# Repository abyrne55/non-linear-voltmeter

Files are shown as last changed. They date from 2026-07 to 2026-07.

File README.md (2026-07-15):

# Non-linear Voltmeter

Arduino-driven 0-16 V panel meter with a Gaussian-weighted non-linear scale that expands resolution around 12 V — designed for monitoring a 12 V DC bus (e.g. Synology NAS power rail).

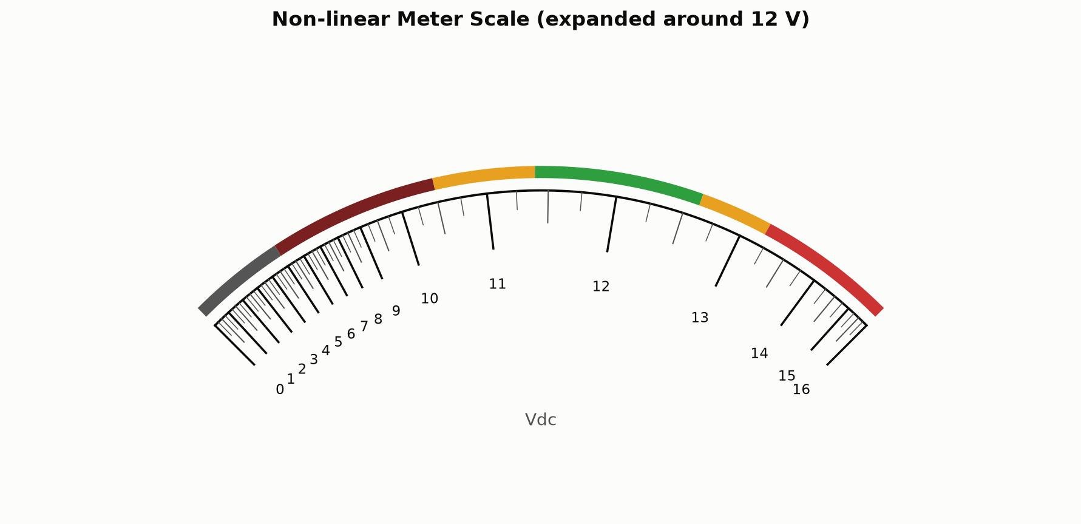
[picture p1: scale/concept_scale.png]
Meter scale


## Circuit

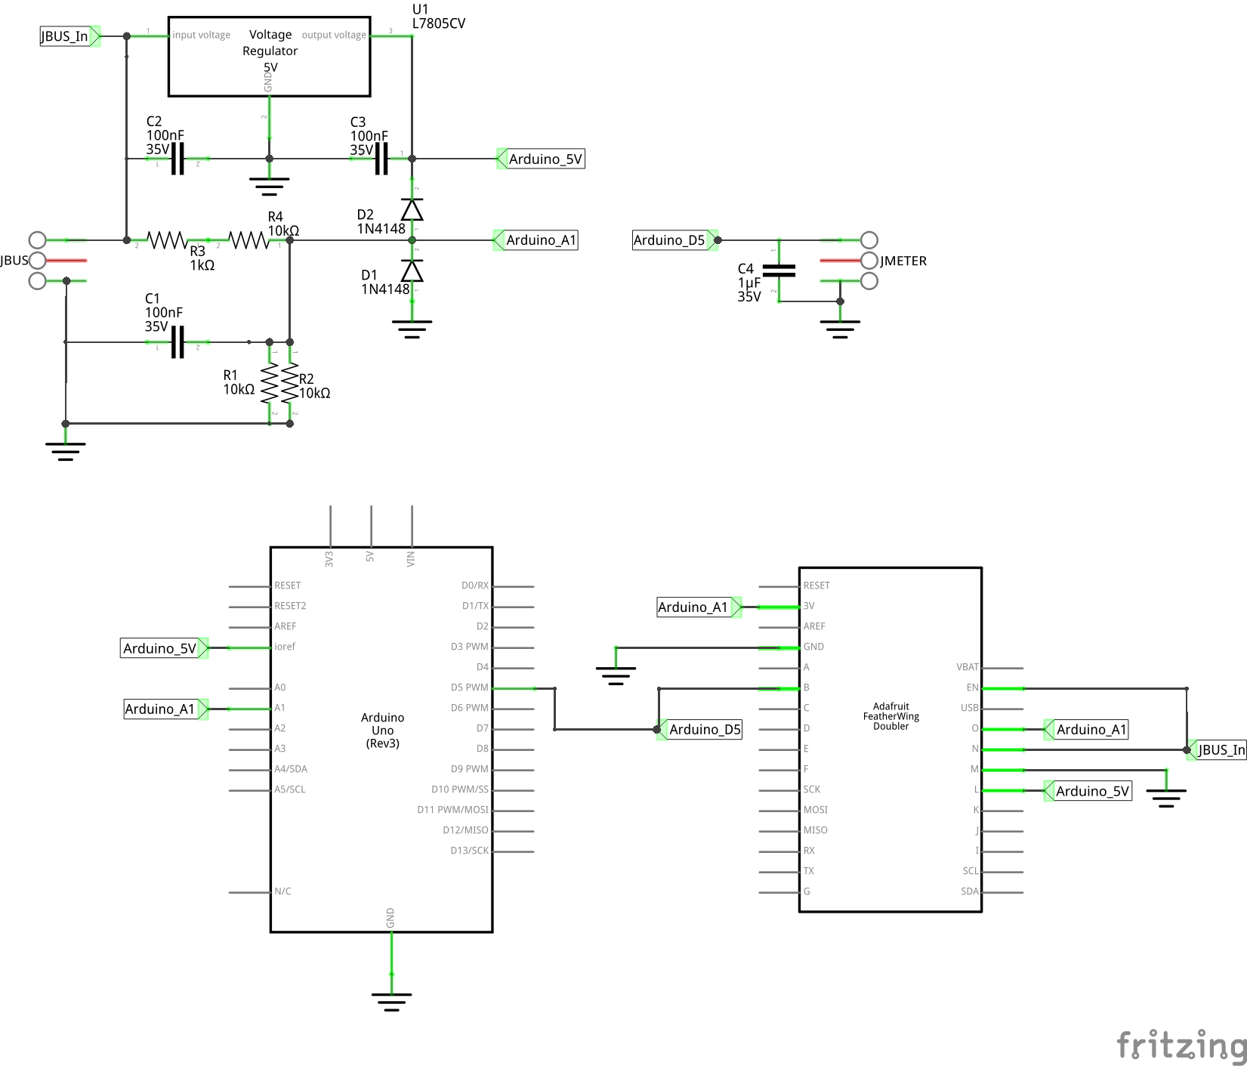
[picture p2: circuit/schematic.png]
Schematic


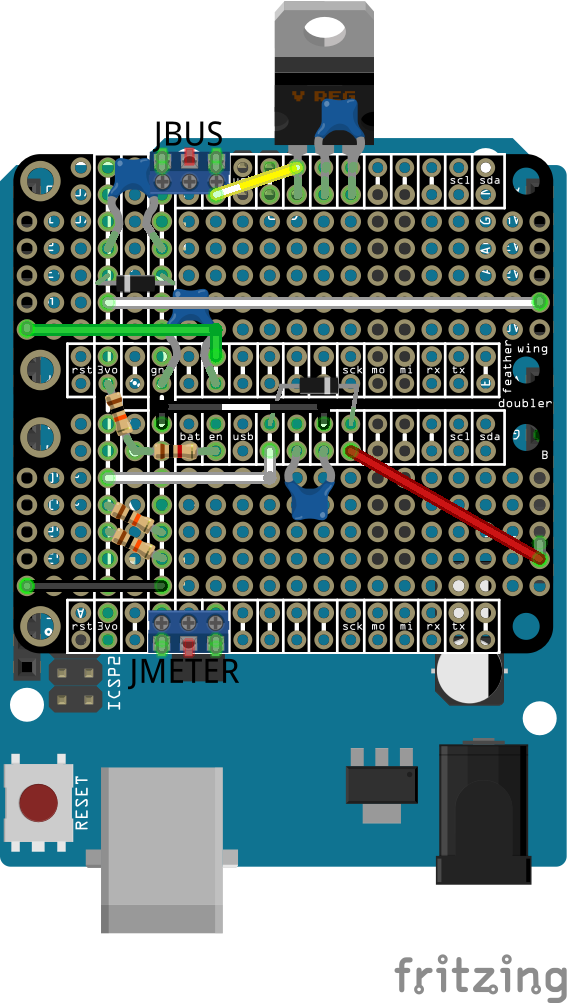
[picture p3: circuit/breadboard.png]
Breadboard layout


The bus voltage is fed through a resistor divider (R1/R2/R3) with diode clamping (D1/D2) for overvoltage protection. An L7805CV regulator (U1) powers the Arduino from the same bus. The PWM output is smoothed by C4 before driving the panel meter.

## How it works

A Gaussian sensitivity function concentrates ~60% of the meter's arc in the 10-14 V range, making small deviations from 12 V easy to read at a glance. A Python script integrates this sensitivity curve to produce a 1024-entry ADC-to-PWM lookup table. The Arduino reads voltage via the resistor divider on A1 (scaled 0-16 V to 0-5 V), applies an EMA filter, and drives an 85C1-style panel meter with PWM on pin 5 (D5).

Color bands on the scale face indicate operating zones:

| Band | Range | Meaning |
|---|---|---|
| Gray | 0-5 V | Device off |
| Maroon | 5-10.5 V | Brownout / corruption risk |
| Amber | 10.5-11.4 V | Brownout warning |
| Green | 11.4-12.6 V | Safe range (±5%) |
| Amber | 12.6-13.2 V | Overvoltage warning |
| Red | 13.2-16 V | Overvoltage damage |

## Simulator

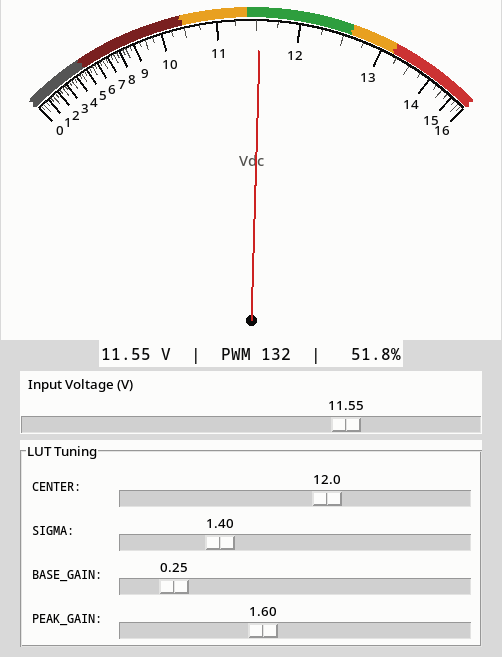
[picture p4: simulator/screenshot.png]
Meter simulator


Interactive Tkinter simulator with needle, slider, and PWM readout:

```
python3 simulator/meter_gui.py
```

## Files

| File | Description |
|---|---|
| `firmware/meter.ino` | Arduino sketch — reads ADC, applies LUT, outputs PWM |
| `firmware/generate_lut.py` | Generates the ADC→PWM lookup table (prints Arduino C array) |
| `firmware/meter_lut.csv` | LUT as CSV (`voltage`, `duty_cycle_pct`) |
| `firmware/voltage_mapping.csv` | Full mapping (`bus_voltage`, `meter_voltage`) |
| `scale/generate_cricut_svg.py` | Generates a 1:1 SVG for Cricut "Print Then Cut" |
| `scale/generate_concept.py` | Renders the non-linear scale face as a PNG (matplotlib) |
| `scale/meter_scale_cricut.svg` | Cricut-ready SVG output |
| `scale/meter_scale_cricut_6x3.57cm.png` | Scale face PNG (transparent background) |
| `scale/concept_scale.png` | Concept visualization of the scale |
| `scale/alignment/` | Alignment validation tools and reference photos |
| `circuit/meter.fzz` | Fritzing project file (schematic + breadboard) |
| `circuit/schematic.png` | Circuit schematic |
| `circuit/breadboard.png` | Breadboard layout |
| `simulator/meter_gui.py` | Interactive Tkinter simulator with needle, slider, and PWM readout |
| `simulator/screenshot.png` | Simulator screenshot |

## Tuning

Edit the parameters at the top of `firmware/generate_lut.py`:

- `CENTER` — voltage the scale expands around (default 12.0)
- `SIGMA` — width of the expanded region (default 1.4)
- `BASE_GAIN` / `PEAK_GAIN` — sensitivity floor vs. peak at center

## Custom Scale Face (Cricut)

Cricut scale face SVG

`scale/generate_cricut_svg.py` generates a 1:1 physical-scale SVG for replacing the factory 0-5 V scale on the Baomain 85C1 with the custom non-linear 0-16 Vdc scale using a Cricut "Print Then Cut" workflow.

```
python3 scale/generate_cricut_svg.py           # produces meter_scale_cricut.svg + .png
python3 scale/generate_cricut_svg.py --ruler   # adds mm ruler ticks for verifying dimensions
```

### Cricut workflow

1. Import `meter_scale_cricut.svg` into Cricut Design Space
2. Select all layers **except** the magenta cut outline → click **Flatten** (merges into a single "Print Then Cut" layer)
3. The magenta cut outline remains as a **Cut** operation
4. Select both the flattened print layer and cut outline → **Attach** (locks relative positioning)
5. Click **Make It** — the Cricut prints the design with registration marks, then cuts the outline
6. Trim and mount the printed scale face onto the meter

### Tuning physical dimensions

All measurements are configurable constants at the top of the script (mm). Print at 100% scale (no fit-to-page) and compare against the original plate. Key parameters:

| Parameter | Default | What it controls |
|---|---|---|
| `PLATE_W` / `PLATE_H` | 60 × 35.7 mm | Overall plate size |
| `ARC_RADIUS` | 31.5 mm | Scale arc radius |
| `PIVOT_X` / `PIVOT_Y` | 30.0 / 39.2 mm | Needle pivot point |
| `NOTCH_W` / `NOTCH_H` | 22.7 / 5.85 mm | Bottom cutout size |
| `TOWER_W` | 1.2 mm | Tower column width flanking the dome |
| `VALLEY_DEPTH` | 2.0 mm | Valley floor height between towers and dome |
| `DOME_N` | 2.283 | Superellipse exponent for dome profile |
| `FILLET_R` | 0.3 mm | Fillet radius at 90° corners |
| `MOUNT_HOLE_*` | 2.5 mm dia, 14/3 mm inset | Screw hole placement |

## License

Public domain — see [UNLICENSE](UNLICENSE).

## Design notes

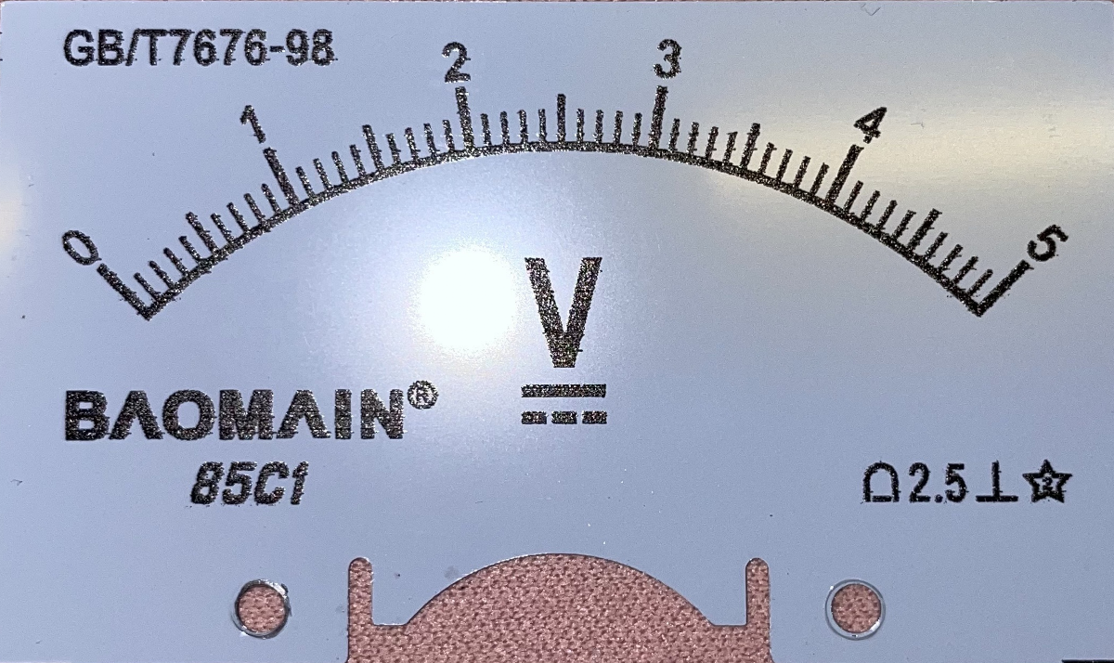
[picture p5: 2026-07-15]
scale/alignment/reference_warped.png

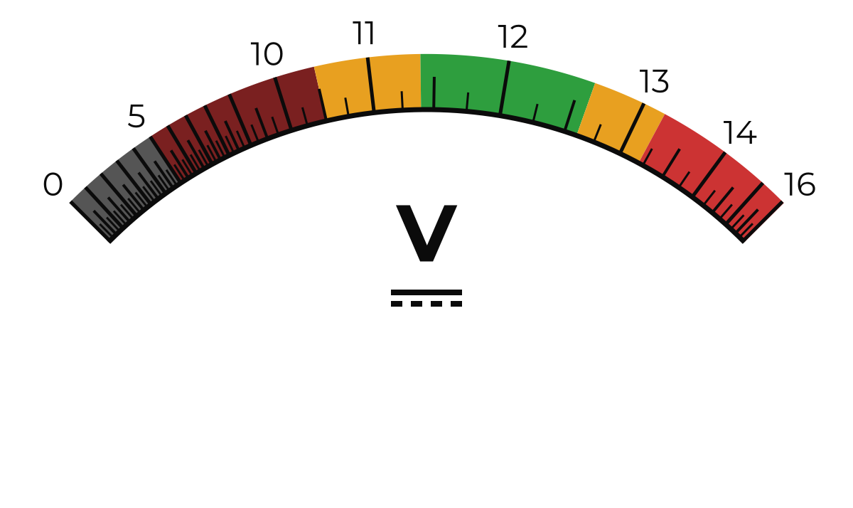
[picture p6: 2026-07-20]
scale/meter_scale_cricut_6x3.57cm.png

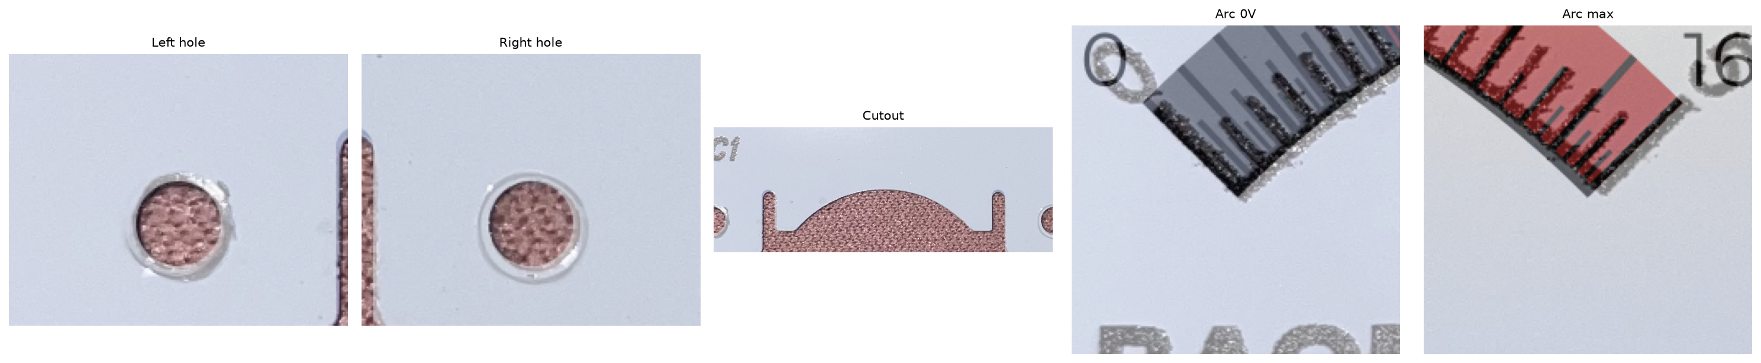
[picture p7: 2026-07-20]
scale/alignment/reference_crops.png

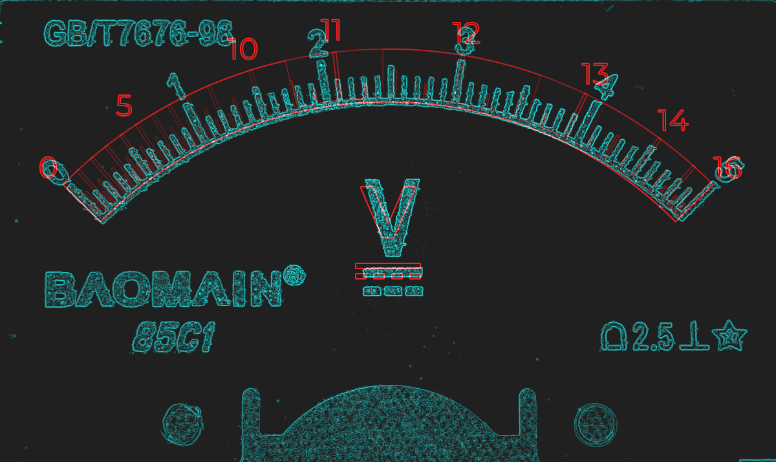
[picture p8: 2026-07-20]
scale/alignment/reference_edges.png

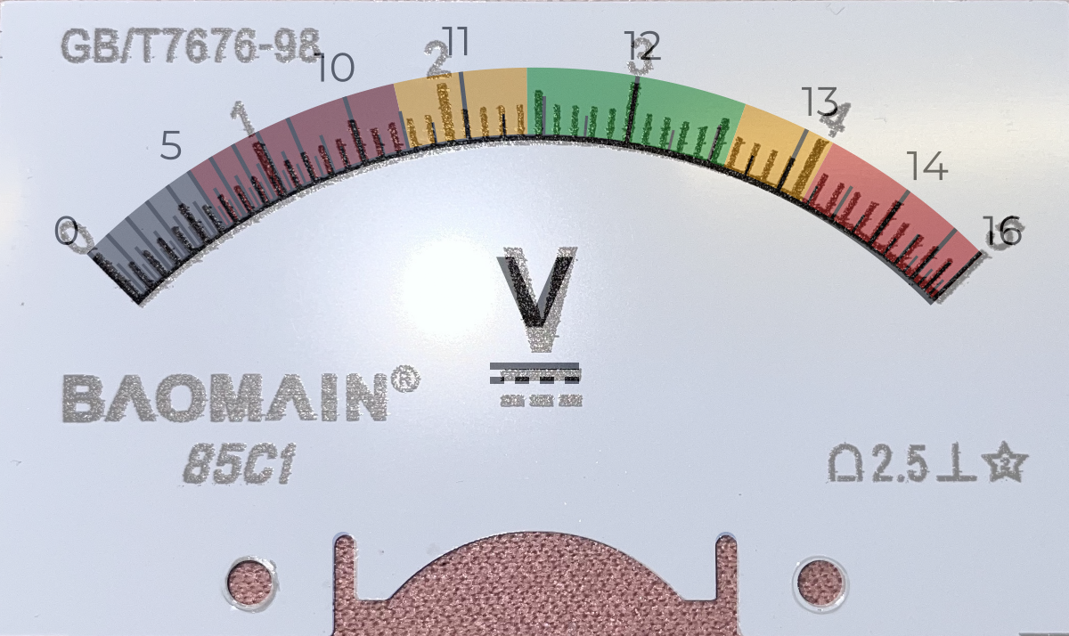
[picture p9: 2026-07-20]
scale/alignment/reference_overlay.png

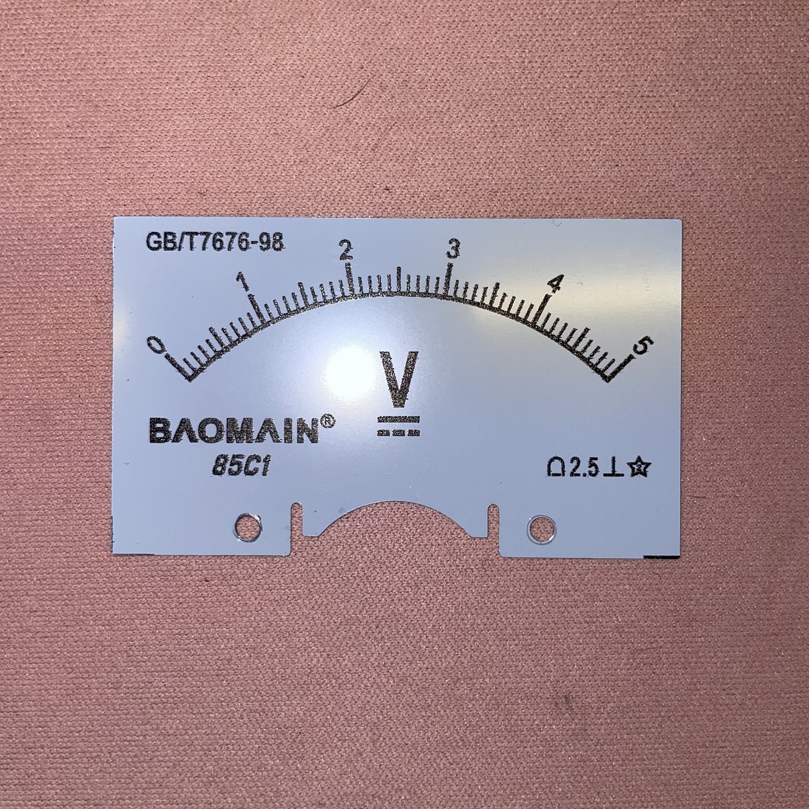
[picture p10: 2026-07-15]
scale/alignment/reference.jpg

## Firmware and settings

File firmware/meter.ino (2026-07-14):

#define DEBUG

const uint8_t PIN_ANALOG = A1;
const uint8_t PIN_PWM    = 5;
const float   V_PER_COUNT = 16.0 / 1024.0;

// Lookup table: ADC value (0-1023) -> PWM output (0-255).
// Generated from meter_lut.csv: a Gaussian-weighted nonlinear mapping
// that expands the scale around 12 V for an 85C1-style panel meter.
static const uint8_t lut[1024] = {
    0,   0,   0,   0,   0,   1,   1,   1,   1,   1,   1,   1,   1,   1,   1,   2,
    2,   2,   2,   2,   2,   2,   2,   2,   2,   3,   3,   3,   3,   3,   3,   3,
    3,   3,   4,   4,   4,   4,   4,   4,   4,   4,   4,   4,   5,   5,   5,   5,
    5,   5,   5,   5,   5,   6,   6,   6,   6,   6,   6,   6,   6,   6,   6,   7,
    7,   7,   7,   7,   7,   7,   7,   7,   7,   8,   8,   8,   8,   8,   8,   8,
    8,   8,   9,   9,   9,   9,   9,   9,   9,   9,   9,   9,  10,  10,  10,  10,
   10,  10,  10,  10,  10,  10,  11,  11,  11,  11,  11,  11,  11,  11,  11,  12,
   12,  12,  12,  12,  12,  12,  12,  12,  12,  13,  13,  13,  13,  13,  13,  13,
   13,  13,  13,  14,  14,  14,  14,  14,  14,  14,  14,  14,  15,  15,  15,  15,
   15,  15,  15,  15,  15,  15,  16,  16,  16,  16,  16,  16,  16,  16,  16,  17,
   17,  17,  17,  17,  17,  17,  17,  17,  17,  18,  18,  18,  18,  18,  18,  18,
   18,  18,  18,  19,  19,  19,  19,  19,  19,  19,  19,  19,  20,  20,  20,  20,
   20,  20,  20,  20,  20,  20,  21,  21,  21,  21,  21,  21,  21,  21,  21,  21,
   22,  22,  22,  22,  22,  22,  22,  22,  22,  23,  23,  23,  23,  23,  23,  23,
   23,  23,  23,  24,  24,  24,  24,  24,  24,  24,  24,  24,  25,  25,  25,  25,
   25,  25,  25,  25,  25,  25,  26,  26,  26,  26,  26,  26,  26,  26,  26,  26,
   27,  27,  27,  27,  27,  27,  27,  27,  27,  28,  28,  28,  28,  28,  28,  28,
   28,  28,  28,  29,  29,  29,  29,  29,  29,  29,  29,  29,  29,  30,  30,  30,
   30,  30,  30,  30,  30,  30,  31,  31,  31,  31,  31,  31,  31,  31,  31,  31,
   32,  32,  32,  32,  32,  32,  32,  32,  32,  32,  33,  33,  33,  33,  33,  33,
   33,  33,  33,  34,  34,  34,  34,  34,  34,  34,  34,  34,  34,  35,  35,  35,
   35,  35,  35,  35,  35,  35,  36,  36,  36,  36,  36,  36,  36,  36,  36,  36,
   37,  37,  37,  37,  37,  37,  37,  37,  37,  37,  38,  38,  38,  38,  38,  38,
   38,  38,  38,  39,  39,  39,  39,  39,  39,  39,  39,  39,  39,  40,  40,  40,
   40,  40,  40,  40,  40,  40,  40,  41,  41,  41,  41,  41,  41,  41,  41,  41,
   42,  42,  42,  42,  42,  42,  42,  42,  42,  42,  43,  43,  43,  43,  43,  43,
   43,  43,  43,  44,  44,  44,  44,  44,  44,  44,  44,  44,  44,  45,  45,  45,
   45,  45,  45,  45,  45,  45,  45,  46,  46,  46,  46,  46,  46,  46,  46,  46,
   47,  47,  47,  47,  47,  47,  47,  47,  47,  47,  48,  48,  48,  48,  48,  48,
   48,  48,  48,  49,  49,  49,  49,  49,  49,  49,  49,  49,  50,  50,  50,  50,
   50,  50,  50,  50,  50,  50,  51,  51,  51,  51,  51,  51,  51,  51,  51,  52,
   52,  52,  52,  52,  52,  52,  52,  52,  53,  53,  53,  53,  53,  53,  53,  53,
   53,  54,  54,  54,  54,  54,  54,  54,  54,  55,  55,  55,  55,  55,  55,  55,
   55,  56,  56,  56,  56,  56,  56,  56,  56,  57,  57,  57,  57,  57,  57,  57,
   57,  58,  58,  58,  58,  58,  58,  58,  59,  59,  59,  59,  59,  59,  59,  60,
   60,  60,  60,  60,  60,  60,  61,  61,  61,  61,  61,  61,  62,  62,  62,  62,
   62,  62,  63,  63,  63,  63,  63,  63,  64,  64,  64,  64,  64,  65,  65,  65,
   65,  65,  66,  66,  66,  66,  66,  67,  67,  67,  67,  68,  68,  68,  68,  69,
   69,  69,  69,  69,  70,  70,  70,  70,  71,  71,  71,  72,  72,  72,  72,  73,
   73,  73,  74,  74,  74,  74,  75,  75,  75,  76,  76,  76,  77,  77,  77,  78,
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
};

static uint16_t filtered = 0;

void setup() {
  pinMode(PIN_PWM, OUTPUT);
  filtered = analogRead(PIN_ANALOG) << 3;
#ifdef DEBUG
  Serial.begin(9600);
#endif
}

void loop() {
  // EMA filter (α ≈ 1/8) to smooth ADC noise
  uint16_t raw = analogRead(PIN_ANALOG);
  filtered += raw - (filtered >> 3);
  uint16_t adc = filtered >> 3;
  if (adc > 1023) adc = 1023;

  uint8_t pwm = lut[adc];
  analogWrite(PIN_PWM, pwm);

#ifdef DEBUG
  static uint16_t loop_count = 0;
  if (++loop_count >= 500) {
    loop_count = 0;
    float v_adc = adc * (5.0 / 1024.0);
    float v_bus = adc * V_PER_COUNT;
    float duty  = pwm / 255.0 * 100.0;
    Serial.print("ADC: "); Serial.print(v_adc, 3); Serial.print(" V  |  ");
    Serial.print("Bus: "); Serial.print(v_bus, 2); Serial.print(" V  |  ");
    Serial.print("PWM: "); Serial.print(pwm); Serial.print("  |  ");
    Serial.print("Duty: "); Serial.print(duty, 1); Serial.println("%");
  }
#endif

  delay(4);
}

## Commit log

2026-07-08 Add Arduino sketch implementing meter LUT
2026-07-14 Add Fritzing schematic and update pin assignments
    Update analog input (A0→A1) and PWM output (pin 10→pin 5) to
    match the Fritzing schematic. Add circuit section to README with
    schematic and breadboard images.
    [meter.fzz]
2026-07-14 Add Cricut-ready 1:1 scale face SVG generator
    Produces a physical-scale (60x35.5mm) SVG with print layers
    (color bands, ticks, labels) and a magenta cut outline for
    Cricut "Print Then Cut" workflow. All text is vectorized.
2026-07-14 Tach-style color bands with ticks on outside of arc
    Color bands now fill the tick region (like a tachometer redline).
    Ticks and labels moved to the outside of the arc. All ticks black,
    major ticks skinnier, bands extend 0.1275mm past tick tips.
2026-07-14 Update notch to elliptical arc cutout from reference photos
    Replaced rectangular notch with a simple elliptical arc (22mm wide,
    6mm peak height) matching the actual 85C1 scale plate shape.
2026-07-14 Update screw hole size and position from measurements
    2.5mm diameter, centered 14mm from edges and 3mm from bottom.
2026-07-14 Use circular arc for notch cutout and add --ruler flag
    Replaced elliptical arc with true circular arc (R=13.1mm) for the
    notch. Added --ruler CLI flag to overlay mm ruler ticks along all
    edges for verifying physical dimensions on test prints.
2026-07-14 Switch to Montserrat font and tweak label sizing
    Larger voltage labels (6.5pt) with adjusted offset (0.18) for
    better readability while maintaining clearance from ticks.
2026-07-14 Make Cricut PNG transparent with size in filename
    PNG now has transparent notch/mounting holes, no magenta cut marks,
    300 DPI, and encodes plate dimensions in filename (60x36mm).
    SVG retains the magenta cut outline for Cricut print-then-cut.
2026-07-15 Add 0.5mm fillet arcs at notch 90° corners for smoother Cricut cuts
2026-07-15 Reorganize repo into firmware/, scale/, circuit/, simulator/ subdirs
    Flat file layout was hard to navigate and invisible to search. Group
    files by function, rename for clarity (e.g. genlut.py → generate_lut.py),
    add .gitignore, fix hardcoded output paths to use Path(__file__).parent,
    update README with new paths/images/dimensions, and set GitHub description
    and topics for discoverability.
    [meter.fzz, meter_lut.csv, voltage_mapping.csv]
2026-07-15 Use 90° arc to match physical scale; add live LUT tuning sliders
    Change simulator and concept generator arc from 110° (145–35) to 90°
    (135–45) to match the Cricut physical scale. Add interactive sliders
    for CENTER, SIGMA, BASE_GAIN, and PEAK_GAIN in the simulator so the
    LUT curve can be adjusted in real time.
2026-07-20 Flush arc ends with endpoint tick faces
    Extend arc and end color bands past 0V/16V tick centers by half the
    major-tick stroke width so the butt-capped arc edge aligns with
    each tick's outer face, eliminating the divot at the junction.
